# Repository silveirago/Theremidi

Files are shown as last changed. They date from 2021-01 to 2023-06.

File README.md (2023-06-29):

# Theremidi

- Full video: https://youtu.be/CWPtxGrBlU8
- Making Music with Arduino: https://go.musiconerd.com/nerd-musician-pro/
- Curso Fazendo Música com Arduino em Português: https://go.musiconerd.com/fazendo-musica-com-arduino

In this video, I am going to show you the Theremidi, a DIY MIDI Theremin, made using an Arduino Pro Micro!

The Theremin was one of the first electronic musical instruments invented in history, by Leo Theremin. It consists of a synthesizer that uses two antennas as capacitive sensors, which track the position of the player's hands, controlling the volume and the pitch. 

However, playing a Theremin is super hard, it requires a lot of practice, and it is very expensive. So, why not have something similar but way cheaper and way easier to play? That's what I did, I created my own MIDI Theremin!

The Theremidi uses two infrared distance sensors, instead of capacitive antennas, and can track the position of your hands in the air. This position is then converted into MIDI notes, or pitch bend - right hand, or MIDI CC - left hand.

There's also an OLED display and some buttons that allow you to change octave, transpose, MIDI channel, and switch between scales and pitch bend!

Material:

- Arduino Pro Micro: https://amzn.to/2Vcz3Nz
- Sharp GP2Y0A41SK0F: https://amzn.to/3biVfha
- Oled Display: https://www.amazon.com/gp/product/B07QW95L1B/ref=ppx_yo_dt_b_asin_title_o00_s00?ie=UTF8&psc=1
- Button that fits in 10mm hole (haven't found a link yet)

Patreon: https://www.patreon.com/musiconerd

Blog: http://www.musiconerd.com

Facebook: https://www.facebook.com/musiconerdmusiconerd

Instagram: http://www.instagram.com/musiconerd

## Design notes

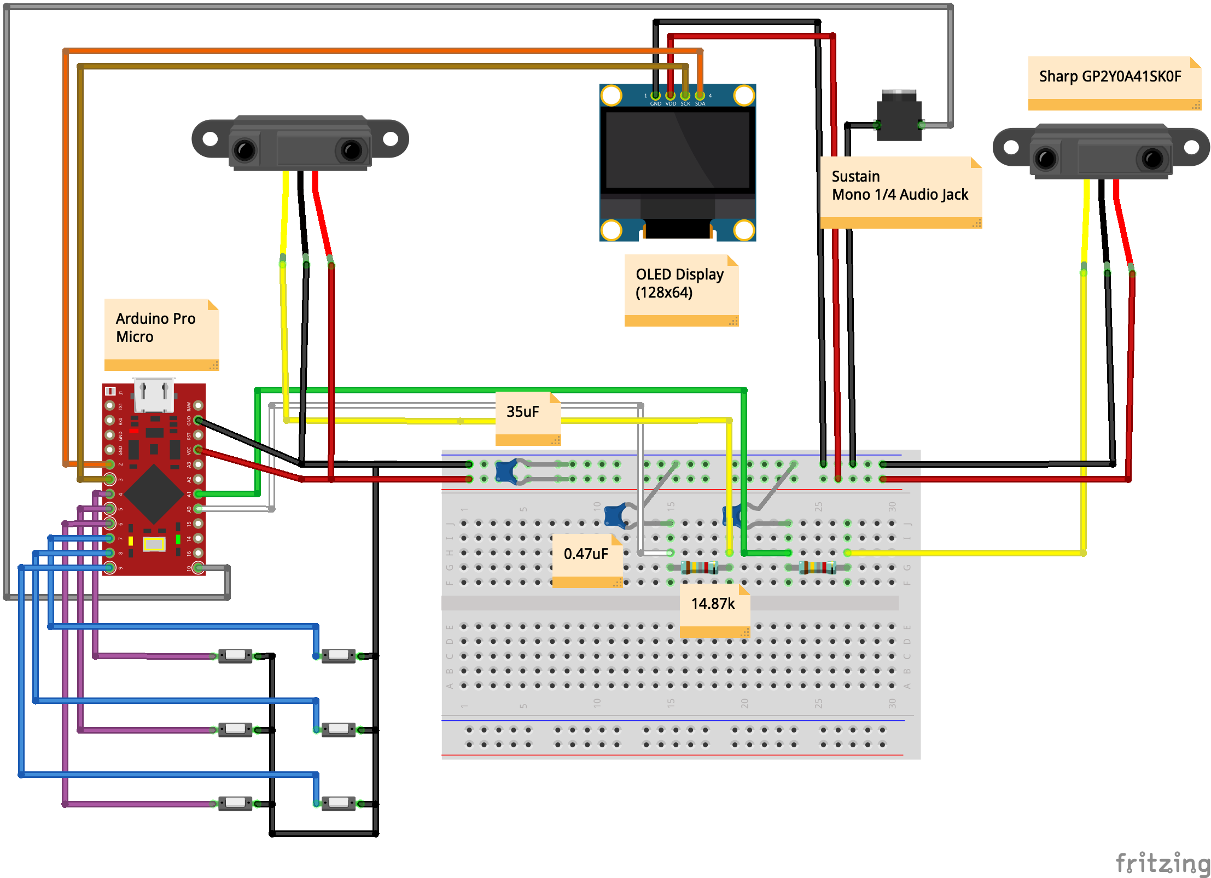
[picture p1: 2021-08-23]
Schematic/Theremidi Schematic.png

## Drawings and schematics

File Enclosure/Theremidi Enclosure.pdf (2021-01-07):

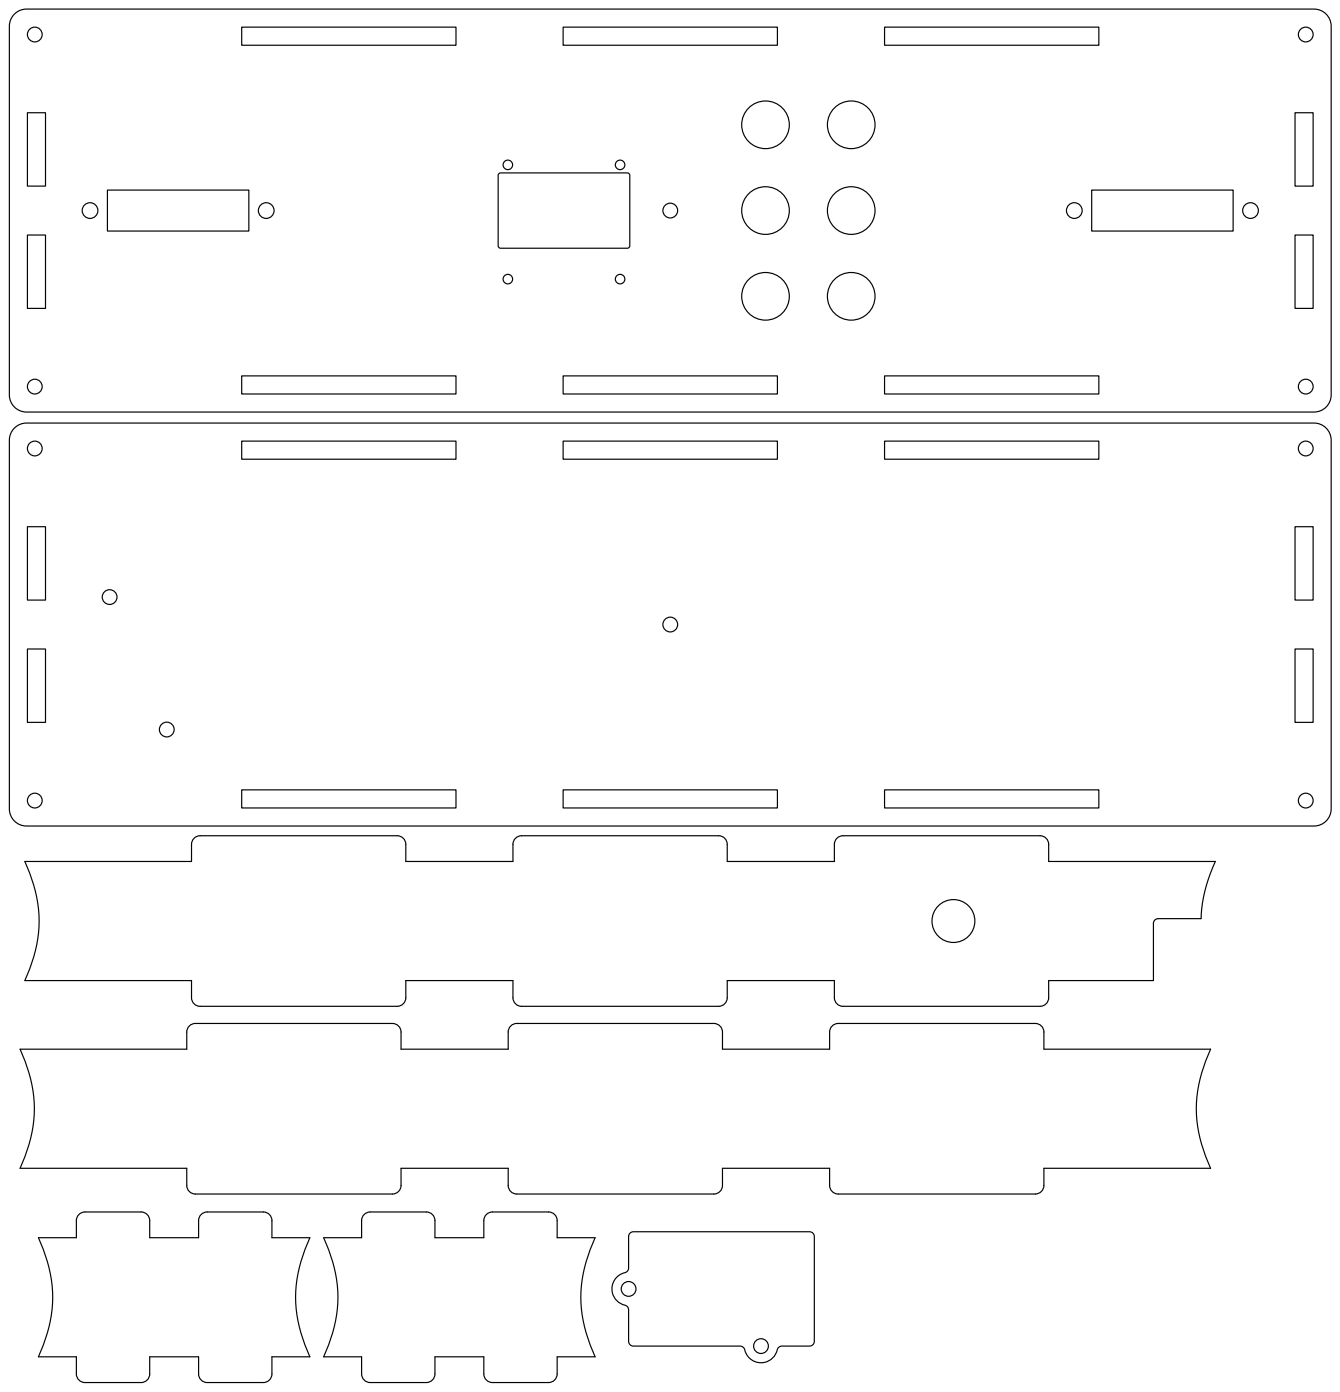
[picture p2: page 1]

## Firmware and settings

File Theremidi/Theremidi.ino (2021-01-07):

/*
  Made by Gustavo Silveira, 2019.
  - This Sketch reads the Arduino's digital and analog ports and send midi notes and midi control change
  - It can use many multiplexers

  http://www.musiconerd.com
  http://www.youtube.com/musiconerd
  http://facebook.com/musiconerdmusiconerd
  http://instagram.com/musiconerd/
  http://www.gustavosilveira.net
  gustavosilveira@musiconerd.com

  If you are using for anything that's not for personal use don't forget to give credit.

  PS: Just change the value that has a comment like " //* "

*/

/////////////////////////////////////////////
// Choosing your board
// Define your board, choose:
// "ATMEGA328" if using ATmega328 - Uno, Mega, Nano...
// "ATMEGA32U4" if using with ATmega32U4 - Micro, Pro Micro, Leonardo...
// "TEENSY" if using a Teensy board
// "DEBUG" if you just want to debug the code in the serial monitor
// you don't need to comment or uncomment any MIDI library below after you define your board

#define ATMEGA32U4 1//* put here the uC you are using, like in the lines above followed by "1", like "ATMEGA328 1", "DEBUG 1", etc.


/////////////////////////////////////////////
// Are you using an I2C Oled Display?
#define USING_DISPLAY 1 //* comment if not using an I2C Oled Display.

/////////////////////////////////////////////
// LIBRARIES
// -- Defines the MIDI library -- //


// if using with ATmega328 - Uno, Mega, Nano...
#ifdef ATMEGA328
#include <MIDI.h>
//MIDI_CREATE_DEFAULT_INSTANCE();

// if using with ATmega32U4 - Micro, Pro Micro, Leonardo...
#elif ATMEGA32U4
#include "MIDIUSB.h"

#endif
// ---- //

//////////////////////
// Threads
#include <Thread.h> // Threads library >> https://github.com/ivanseidel/ArduinoThread
#include <ThreadController.h> // Same as above

//////////////////////
// Average
#include <Average.h>


//////////////////////
// Oled Display I2C
#ifdef USING_DISPLAY
//#include <Adafruit_GFX.h>  // Include core graphics library for the display
#include <Adafruit_SSD1306.h>  // Include Adafruit_SSD1306 library to drive the display
//#include <Fonts/FreeMonoBold12pt7b.h>  // Add a custom font
//#include <Fonts/FreeMono9pt7b.h>  // Add a custom font
Adafruit_SSD1306 display(128, 64);  // Create display - size of the display in pixels
#endif

//////////////////////
// scaleNotes
//#include "scaleNames.h"
//#include "scales.h"
//#include "notes.h"

/////////////////////////////////////////////
// BUTTONS
const int N_BUTTONS = 7; //*  total numbers of buttons. Number of buttons in the Arduino + number of buttons on multiplexer 1 + number of buttons on multiplexer 2...
const int N_BUTTONS_ARDUINO = 7; //* number of buttons connected straight to the Arduino (in order)
const int BUTTON_ARDUINO_PIN[N_BUTTONS] = {4, 5, 6, 7, 8, 9, 10}; //* pins of each button connected straight to the Arduino

int buttonCState[N_BUTTONS] = {0};        // stores the button current value
int buttonPState[N_BUTTONS] = {0};        // stores the button previous value

//#define pin13 1 // uncomment if you are using pin 13 (pin with led), or comment the line if it is not
byte pin13index = 12; //* put the index of the pin 13 of the buttonPin[] array if you are using, if not, comment

// debounce
unsigned long lastDebounceTime[N_BUTTONS] = {0};  // the last time the output pin was toggled
unsigned long debounceDelay = 20;    //* the debounce time; increase if the output flickers


/////////////////////////////////////////////
// POTENTIOMETERS
const int N_POTS = 2; //* total numbers of pots (slide & rotary). Number of pots in the Arduino + number of pots on multiplexer 1 + number of pots on multiplexer 2...
const int N_POTS_ARDUINO = 2; //* number of pots connected straight to the Arduino
const int POT_ARDUINO_PIN[N_POTS_ARDUINO] = {A0, A1}; //* pins of each pot connected straight to the Arduino

//#define USING_CUSTOM_CC_N 1 //* comment if not using CUSTOM CC NUMBERS, uncomment if using it.
#ifdef USING_CUSTOM_CC_N
int POT_CC_N[N_POTS] = {1, 2, 3, 4, 5, 6, 7, 8}; // Add the CC NUMBER of each pot you want
#endif


int potCState[N_POTS] = {0}; // Current state of the pot
int potPState[N_POTS] = {0}; // Previous state of the pot
int potVar[N_POTS] = {0}; // Difference between the current and previous state of the pot

int reading[N_POTS] = {0};
int filteredVal[N_POTS] = {0};
int scaledVal[N_POTS] = {0};
int rangedVal[N_POTS] = {0};

int potMidiCState[N_POTS] = {0}; // Current state of the midi value
int potMidiPState[N_POTS] = {0}; // Previous state of the midi value

const int TIMEOUT[3] = {300, 300}; //* Amount of time the potentiometer will be read after it exceeds the varThreshold[i]
const int varThreshold[3] = {3, 3}; //* Threshold for the potentiometer signal variation
boolean potMoving[3] = {true}; // If the potentiometer is moving
unsigned long PTime[3] = {0}; // Previously stored time
unsigned long timer[3] = {0}; // Stores the time that has elapsed since the timer was reset

// one pole filter
// y[n] = A0 * x[n] + B1 * y[n-1];
// A = 0.15 and B = 0.85
float filterA = 0.15;
float filterB = 0.85;

/////////////////////////////////////////////
// THREADS
// This libs create a "fake" thread. This means you can make something happen every x milisseconds
// We can use that to read something in an interval, instead of reading it every single loop
// In this case we'll read the potentiometers in a thread, making the reading of the buttons faster
ThreadController cpu; //thread master, where the other threads will be added
Thread threadIR0; // thread to control the pots
Thread threadIR1;

/////////////////////////////////////////////
// DISPLAY
byte display_pos_x = 0;
byte display_pos_y = 0;
byte display_text_size = 2;

/////////////////////////////////////////////
// IR
int IR_range[2] = {90, 530}; // the min reading you want the IR to have
//int IR_max_reading[2] = {300, 300};

int IR_min_val[2] = {0, 0}; // the min val you want the IR to output
int IR_max_val[2] = {127, 13};

byte IR_val[2] = {0}; // IR actual value
byte IR_Pval[2] = {0}; // IR previous value

float IR_curve = 1; // for the fscale function

boolean note_is_playing = false;

/////////////////////////////////////////////
// Average
byte averageSize[2] = {10, 15};

Average<float> ave[2] = {
  Average<float> (averageSize[0]),
  Average<float> (averageSize[1])
};


/////////////////////////////////////////////
// MIDI STUFF
int MIDI_CH = 0; //* MIDI channel to be used
byte NOTE = 48; //* Lowest NOTE to be used - The root
byte CC = 7; //* cc to be used in the left sensor
byte sustainCC = 64; //* cc for the sustain pedal
boolean rootMenuIsOn = false;

boolean pitchBendIsOn = false;
boolean pitchBendMenuIsOn = false;
boolean pitchBendIsPlaying = false;

int pitchBendVal = 0;
int pitchBendPVal = 0;

/////////////////////////////////////////////
// scaleNotes
byte scaleIndex = 0;
int octaveIndex = 2;
int octave[5] = { -24, -12, 0, 12, 24};

const byte SCALE_NUM = 4; // number of scales
const byte NOTE_NUM = 16; // number of notes in the scales
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

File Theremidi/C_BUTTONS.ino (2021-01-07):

/////////////////////////////////////////////
// BUTTONS
void buttons() {

  // read pins from arduino
  for (int i = 0; i < N_BUTTONS_ARDUINO; i++) {
    buttonCState[i] = digitalRead(BUTTON_ARDUINO_PIN[i]);
  }

  for (int i = 0; i < N_BUTTONS; i++) { // Read the buttons connected to the Arduino

    if ((millis() - lastDebounceTime[i]) > debounceDelay) {

      if (buttonPState[i] != buttonCState[i]) {
        lastDebounceTime[i] = millis();

        if (buttonCState[i] == LOW) {
          // DO STUFF

          //#ifdef DEBUG
          //Serial.print(i);
          //Serial.print(" ");
          //Serial.println(buttonCState[i]);
          //#endif

          // if midi channel buttons are pressed at the same time they act as a shift button
          // then you can use the octave buttons to change the NOTE (root)
          while ((buttonCState[2] == LOW) && (buttonCState[5] == LOW)) {
            if (rootMenuIsOn == false) {
              rootMenuIsOn = true;
              //Serial.println("rootMenu Is True");
            }
            rootMenu();
          }

          // If both scale buttons are pressed you change the mode of the right sensor
          // between notes and pitch bend

          if ((buttonCState[0] == LOW) && (buttonCState[3] == LOW)) {
            pitchBendIsOn = !pitchBendIsOn;

            if (pitchBendIsOn == true) {
              threadIR1.setInterval(2); // every how many millisiconds
            } else {
              threadIR1.setInterval(20); // every how many millisiconds
            }

            printDisplay(scaleNames[scaleIndex], NOTE % 12, octave[octaveIndex], MIDI_CH, pitchBendNames[pitchBendIsOn]);
            pitchBendMenuIsOn = true;

#ifdef DEBUG
            Serial.print("Pitch Bend menu is ");
            Serial.println(pitchBendMenuIsOn);
            Serial.print("Pitch bend: ");
            Serial.println(pitchBendIsOn);
#endif

          }


          // printDisplay(scaleNames[scaleIndex], NOTE % 12, octave[octaveIndex], MIDI_CH, pitchBendNames[pitchBendIsOn]);

          // sustain pedal
          if (i == 6) {

#ifdef ATMEGA32U4

            controlChange(MIDI_CH, sustainCC, 127);//  (channel, CC number,  CC value)
            MidiUSB.flush();
#endif

#ifdef DEBUG
            Serial.println("Sustain on");
#endif

          }
        }

        else { // if buttons are not pressed

          if ((rootMenuIsOn == false) && (pitchBendMenuIsOn == false)) { // if menus are not on

            switch (i) {
              case 0:
                scaleIndex--;
                scaleIndex %= 4;
                printDisplay(scaleNames[scaleIndex], NOTE % 12, octave[octaveIndex], MIDI_CH, pitchBendNames[pitchBendIsOn]);

#ifdef DEBUG
                Serial.print("Scale: ");
                Serial.println(scaleNames[scaleIndex]);
#endif

                break;
              case 3:
                scaleIndex++;
                scaleIndex %= 4;
                printDisplay(scaleNames[scaleIndex], NOTE % 12, octave[octaveIndex], MIDI_CH, pitchBendNames[pitchBendIsOn]);

#ifdef DEBUG
                Serial.print("Scale: ");
                Serial.println(scaleNames[scaleIndex]);
#endif

                break;
              case 1:
                octaveIndex--;
                if (octaveIndex < 1) octaveIndex = 0;
                printDisplay(scaleNames[scaleIndex], NOTE % 12, octave[octaveIndex], MIDI_CH, pitchBendNames[pitchBendIsOn]);

#ifdef DEBUG
                Serial.print("Octave: ");
                Serial.println(octave[octaveIndex]);
                //Serial.println(octaveIndex);
#endif

                break;
              case 4:
                octaveIndex++;
                if (octaveIndex > 4) octaveIndex = 4;
                printDisplay(scaleNames[scaleIndex], NOTE % 12, octave[octaveIndex], MIDI_CH, pitchBendNames[pitchBendIsOn]);

#ifdef DEBUG
                Serial.print("Octave: ");
                Serial.println(octave[octaveIndex]);
                //Serial.println(octaveIndex);
#endif

                break;
              case 2:
                MIDI_CH--;
                if (MIDI_CH < 0) MIDI_CH = 0;
                printDisplay(scaleNames[scaleIndex], NOTE % 12, octave[octaveIndex], MIDI_CH, pitchBendNames[pitchBendIsOn]);

#ifdef DEBUG
                Serial.print("MIDI Channel: ");
                Serial.println(MIDI_CH);
#endif

                break;
              case 5:
                MIDI_CH++;
                if (MIDI_CH > 15) MIDI_CH = 15;
                printDisplay(scaleNames[scaleIndex], NOTE % 12, octave[octaveIndex], MIDI_CH, pitchBendNames[pitchBendIsOn]);

#ifdef DEBUG
                Serial.print("MIDI Channel: ");
                Serial.println(MIDI_CH);
#endif

                break;
            }
          }

          if (i == 6) { // sustain pedal off

#ifdef ATMEGA32U4

            controlChange(MIDI_CH, sustainCC, 0);//  (channel, CC number,  CC value)
            MidiUSB.flush();
#endif

#ifdef DEBUG
            Serial.println("Sustain off");
#endif

          }

          //#ifdef DEBUG
          //Serial.print(i);
          //Serial.print(" ");
          //Serial.println(buttonCState[i]);
          //#endif
        }

        buttonPState[i] = buttonCState[i];
      }

    }
  }

  // turns off the root menu when both octave buttons are off
  if (rootMenuIsOn == true) {
    if ((buttonCState[2] == HIGH) && (buttonCState[5] == HIGH)) {
      rootMenuIsOn = false;

#ifdef DEBUG
      Serial.println("rootMenu Is Off");
#endif

    }
  }

  // turns off the pitch bend menu when both scale buttons are off
  if (pitchBendMenuIsOn == true) {
    if ((buttonCState[0] == HIGH) && (buttonCState[3] == HIGH)) {
      pitchBendMenuIsOn = false;

#ifdef DEBUG
      Serial.print("Pitch Bend menu is ");
      Serial.println(pitchBendMenuIsOn);
#endif

    }
  }
}

/////////////////////////////////////////////
// create a menu to change the root note pressing
//both ocatve buttons at the same time

void rootMenu() {

  int index[2] = {1, 4};

  // read pins from arduino
  for (int i = 0; i < N_BUTTONS_ARDUINO; i++) {
    buttonCState[i] = digitalRead(BUTTON_ARDUINO_PIN[i]);
  }

  for (int i = 0; i < 2; i++) {
    //    buttonCState[index[i]] = digitalRead(BUTTON_ARDUINO_PIN[index[i]]);

    if ((millis() - lastDebounceTime[index[i]]) > debounceDelay) {

      if (buttonPState[index[i]] != buttonCState[index[i]]) {
        lastDebounceTime[index[i]] = millis();

        if (buttonCState[index[i]] == LOW) {
          // DO STUFF

          switch (i) {
            case 0:
              NOTE--;
              if (NOTE < 36) NOTE = 36;
              printDisplay(scaleNames[scaleIndex], NOTE % 12, octave[octaveIndex], MIDI_CH, pitchBendNames[pitchBendIsOn]);
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

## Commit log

2021-01-07 all files added
    [Theremidi Schematic.fzz]
2021-07-21 sustain pedal added
    [Theremidi Schematic.fzz]
2021-07-21 sustain jack added
    [Theremidi Schematic.fzz]
2021-08-23 schematic 5v and gnd fixed
    [Theremidi Schematic.fzz]
